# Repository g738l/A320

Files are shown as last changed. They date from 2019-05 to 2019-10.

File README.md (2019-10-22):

# A320
Simulation LED Anti-Collision Lighting System for Airbus A320 Family

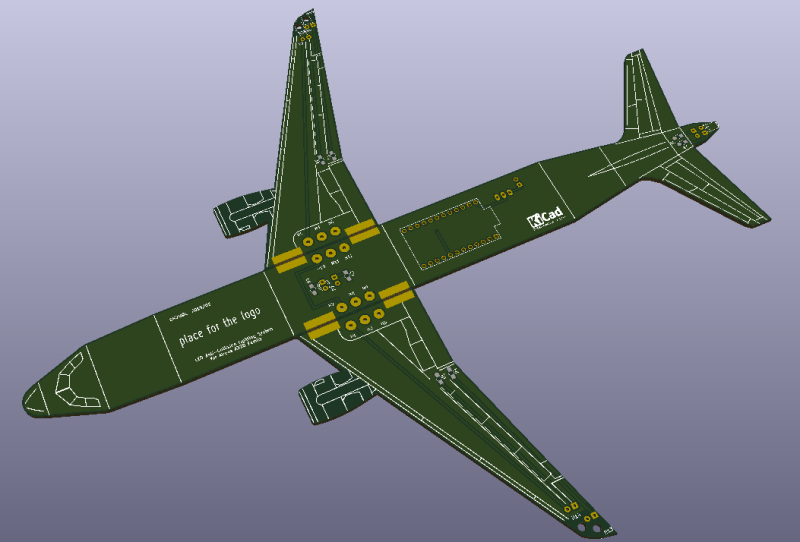
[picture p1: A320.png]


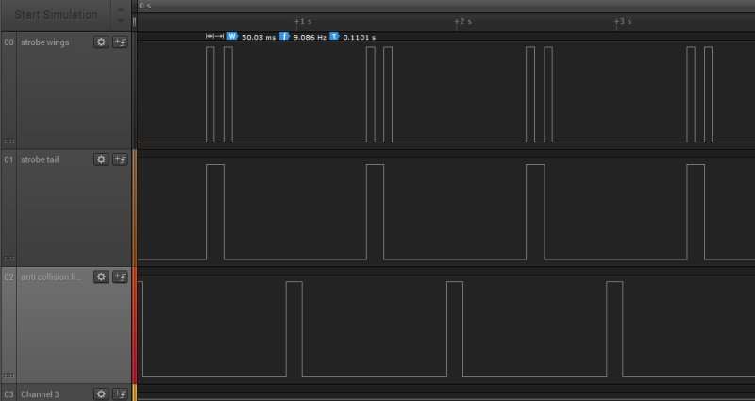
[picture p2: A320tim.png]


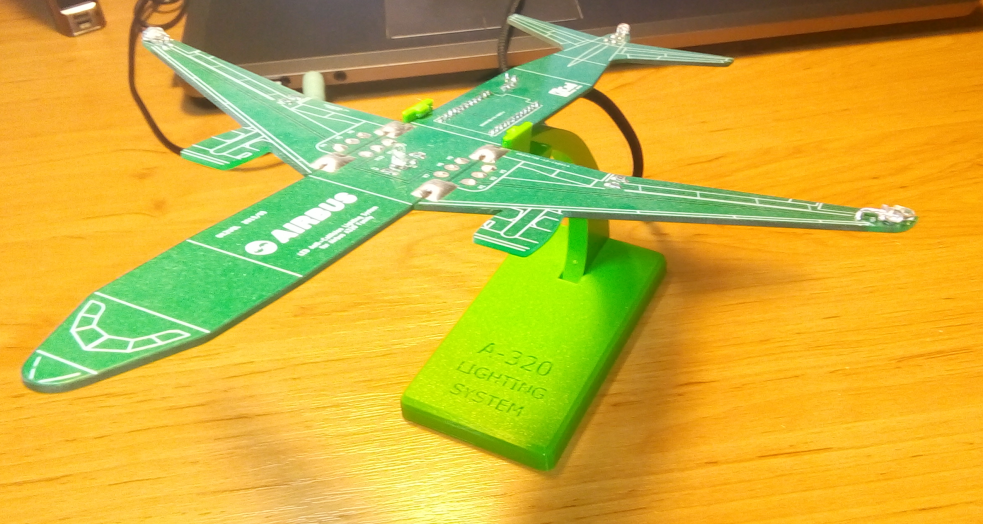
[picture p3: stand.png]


## License
This project is released under the Creative Commons Attribution-NonCommercial-ShareAlike 3.0 (CC-BY-NC-SA 3.0, https://creativecommons.org/licenses/by-nc-sa/3.0/) license. You may edit and share it as you like, as long as credit is given and the license is not changed. You can build as many boards for you and your friends as you like and you can even sell it to them to cover your costs, **however it is strictly forbidden to turn this into a commercial product! You are not allowed to build and sell these boards for profit!**

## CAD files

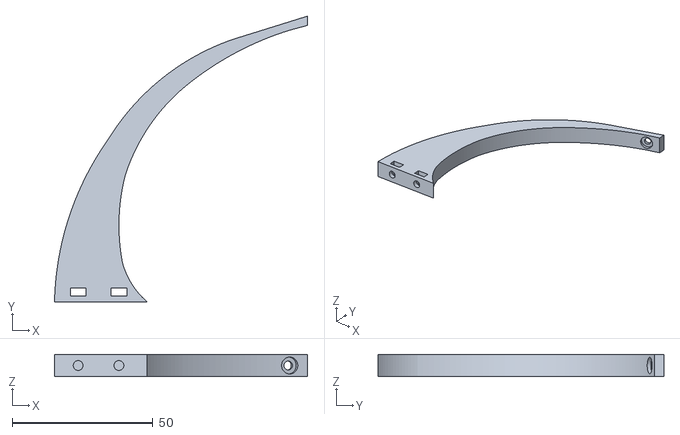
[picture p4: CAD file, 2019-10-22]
3Dstand/A320stand_upright.stl
90.0 x 101.7 x 8.00

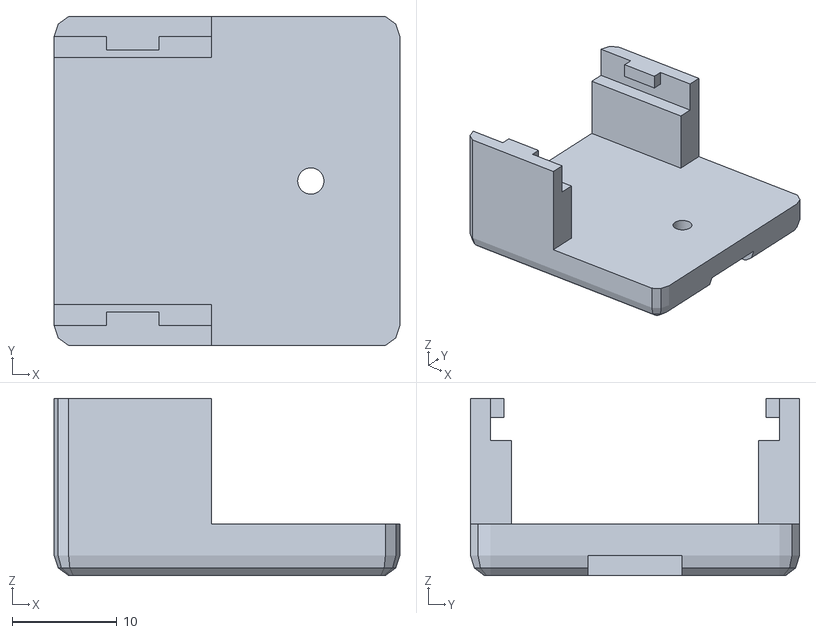
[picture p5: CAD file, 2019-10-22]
3Dstand/A320attachment.stl
33.0 x 31.4 x 16.9

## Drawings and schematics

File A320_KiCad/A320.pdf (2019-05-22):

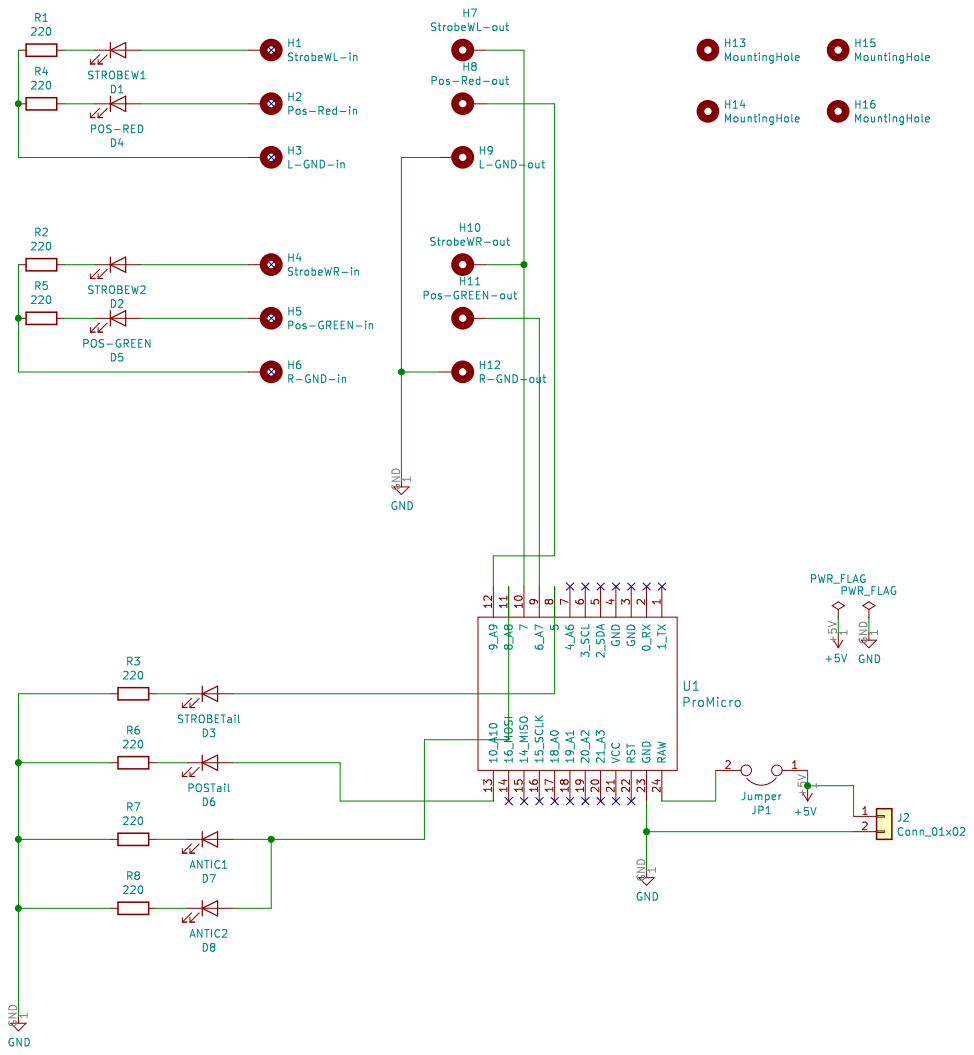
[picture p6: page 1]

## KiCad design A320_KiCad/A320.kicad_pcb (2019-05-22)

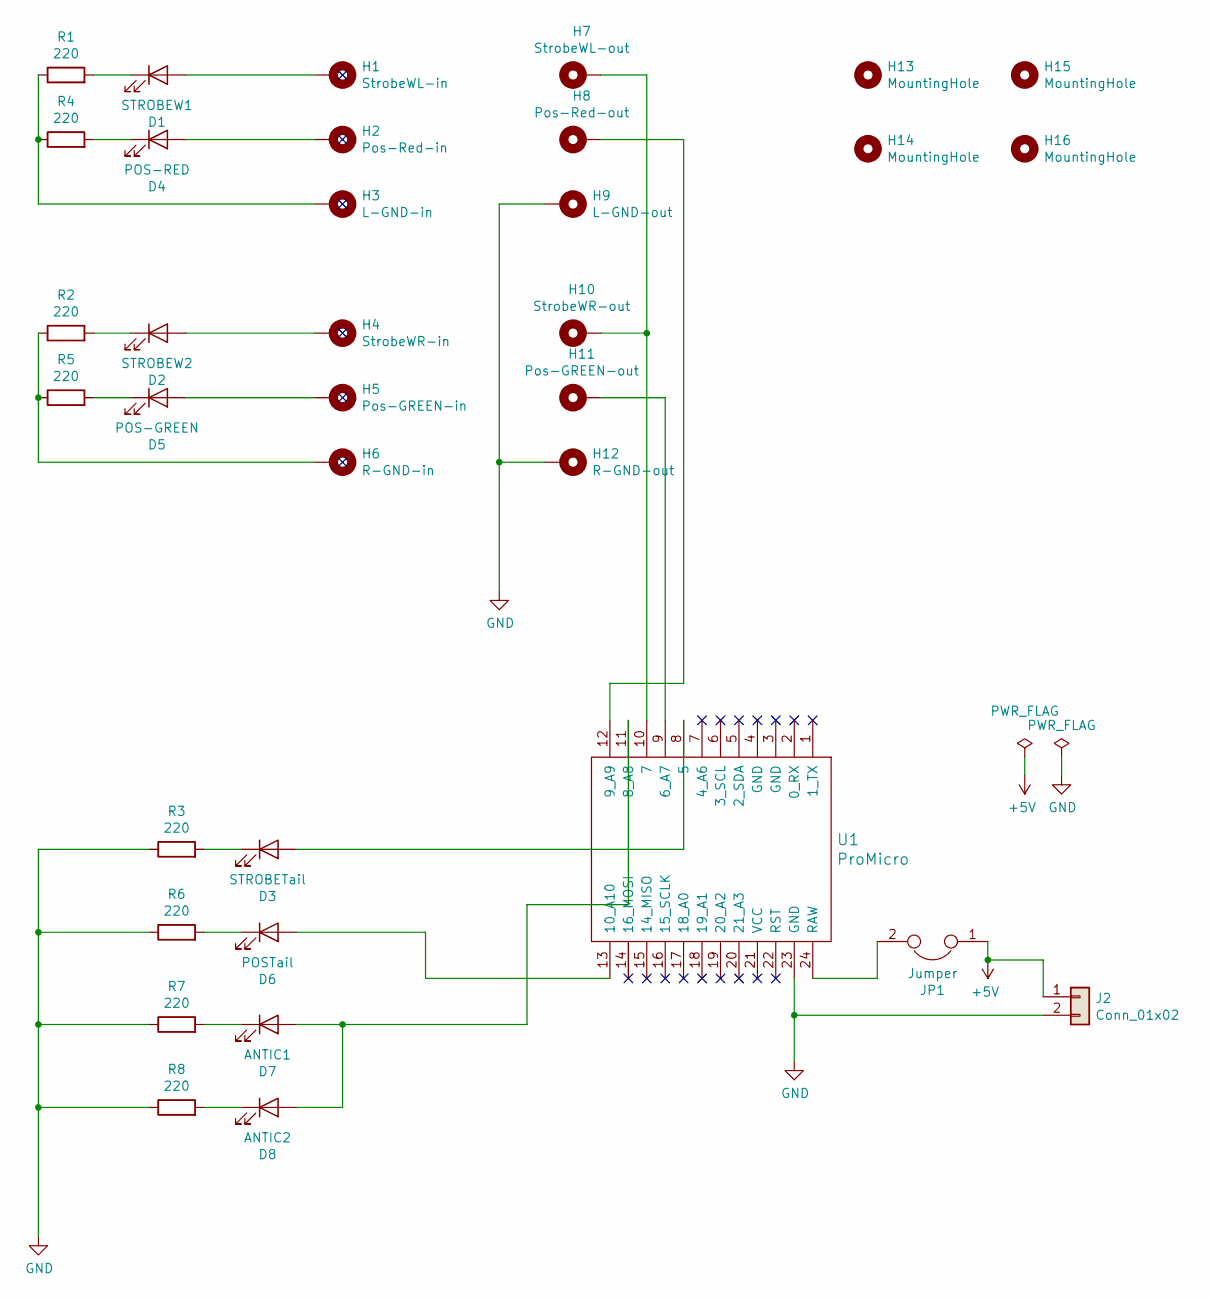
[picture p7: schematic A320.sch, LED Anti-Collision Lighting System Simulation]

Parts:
D1: STROBEW1; LED_D3.0mm_Horizontal_O3.81mm_Z2.0mm
D2: STROBEW2; LED_D3.0mm_Horizontal_O3.81mm_Z2.0mm
D3: STROBETail; LED_D3.0mm_Horizontal_O1.27mm_Z2.0mm
D4: POS-RED; LED_D3.0mm_Horizontal_O1.27mm_Z2.0mm
D5: POS-GREEN; LED_D3.0mm_Horizontal_O1.27mm_Z2.0mm
D6: POSTail; LED_D3.0mm_Horizontal_O3.81mm_Z2.0mm
D7: ANTIC1; LED_D3.0mm_FlatTop
D8: ANTIC2; LED_D3.0mm_FlatTop
H1: StrobeWL-in; SolderWirePad_single_1-2mmDrill
H2: Pos-Red-in; SolderWirePad_single_1-2mmDrill
H3: L-GND-in; SolderWirePad_single_1-2mmDrill
H4: StrobeWR-in; SolderWirePad_single_1-2mmDrill
H5: Pos-GREEN-in; SolderWirePad_single_1-2mmDrill
H6: R-GND-in; SolderWirePad_single_1-2mmDrill
H7: StrobeWL-out; SolderWirePad_single_1-2mmDrill
H8: Pos-Red-out; SolderWirePad_single_1-2mmDrill
H9: L-GND-out; SolderWirePad_single_1-2mmDrill
H10: StrobeWR-out; SolderWirePad_single_1-2mmDrill
H11: Pos-GREEN-out; SolderWirePad_single_1-2mmDrill
H12: R-GND-out; SolderWirePad_single_1-2mmDrill
H13, H14, H15, H16: MountingHole; MountingHole_2.5mm
J2: Conn_01x02; Pin_Header_Angled_1x02_Pitch2.54mm
JP1: Jumper; ON-OFF-SWITH
R1, R2, R3, R4, R5, R6, R7, R8: 220; R_0805_HandSoldering
U1: ProMicro

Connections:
+5V: J2.1, JP1.1
GND: H9.1, H12.1, J2.2, R3.1, R6.1, R7.1, R8.1, U1.23 (GND)
unnamed: D1.1 (K), R1.2
unnamed: D1.2 (A), H1.1
unnamed: D2.1 (K), R2.2
unnamed: D2.2 (A), H4.1
unnamed: D3.1 (K), R3.2
unnamed: D3.2 (A), U1.8 (5)
unnamed: D4.1 (K), R4.2
unnamed: D4.2 (A), H2.1
unnamed: D5.1 (K), R5.2
unnamed: D5.2 (A), H5.1
unnamed: D6.1 (K), R6.2
unnamed: D6.2 (A), U1.13 (10_A10)
unnamed: D7.1 (K), R7.2
unnamed: D7.2 (A), D8.2 (A), U1.11 (8_A8)
unnamed: D8.1 (K), R8.2
unnamed: H3.1, R1.1, R4.1
unnamed: H6.1, R2.1, R5.1
unnamed: H8.1, U1.12 (9_A9)
unnamed: H7.1, H10.1, U1.10 (7)
unnamed: H11.1, U1.9 (6_A7)
unnamed: JP1.2, U1.24 (RAW)

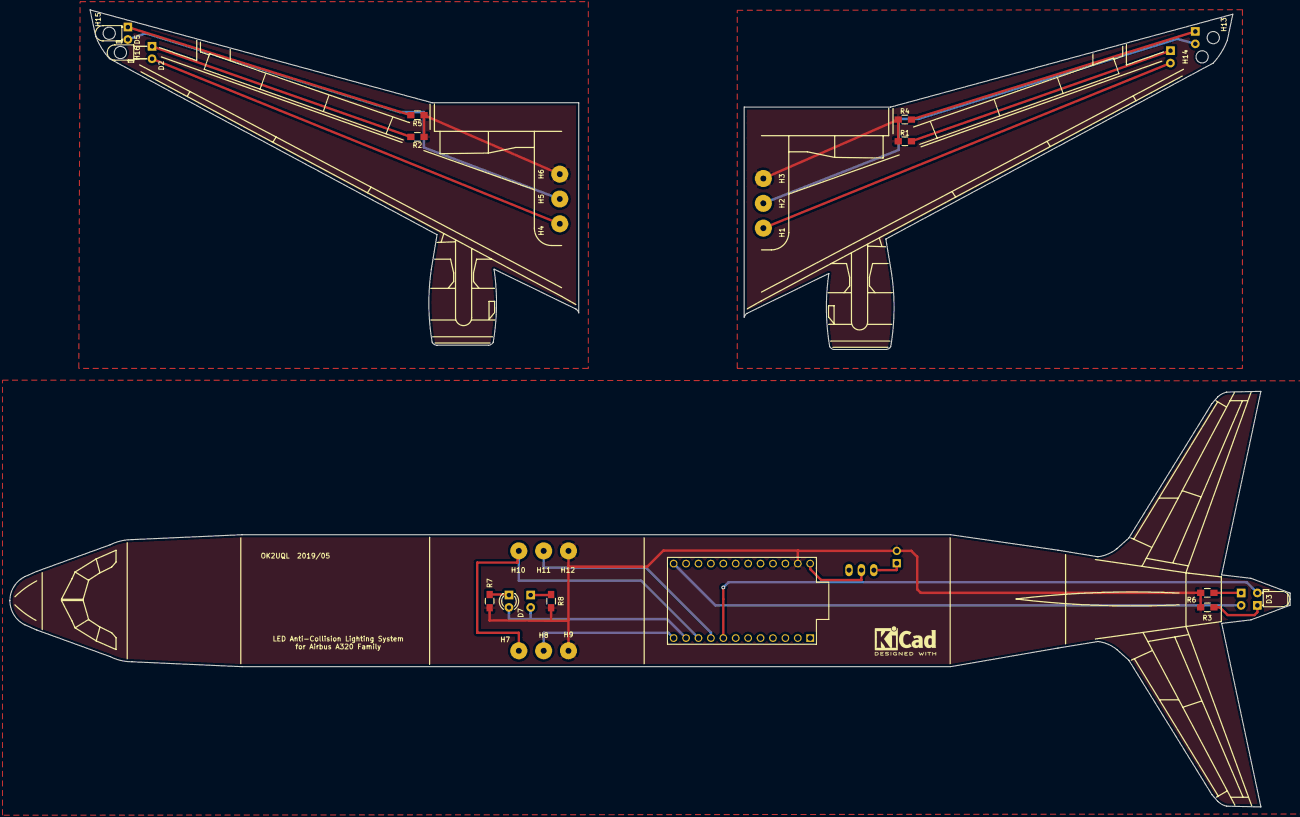
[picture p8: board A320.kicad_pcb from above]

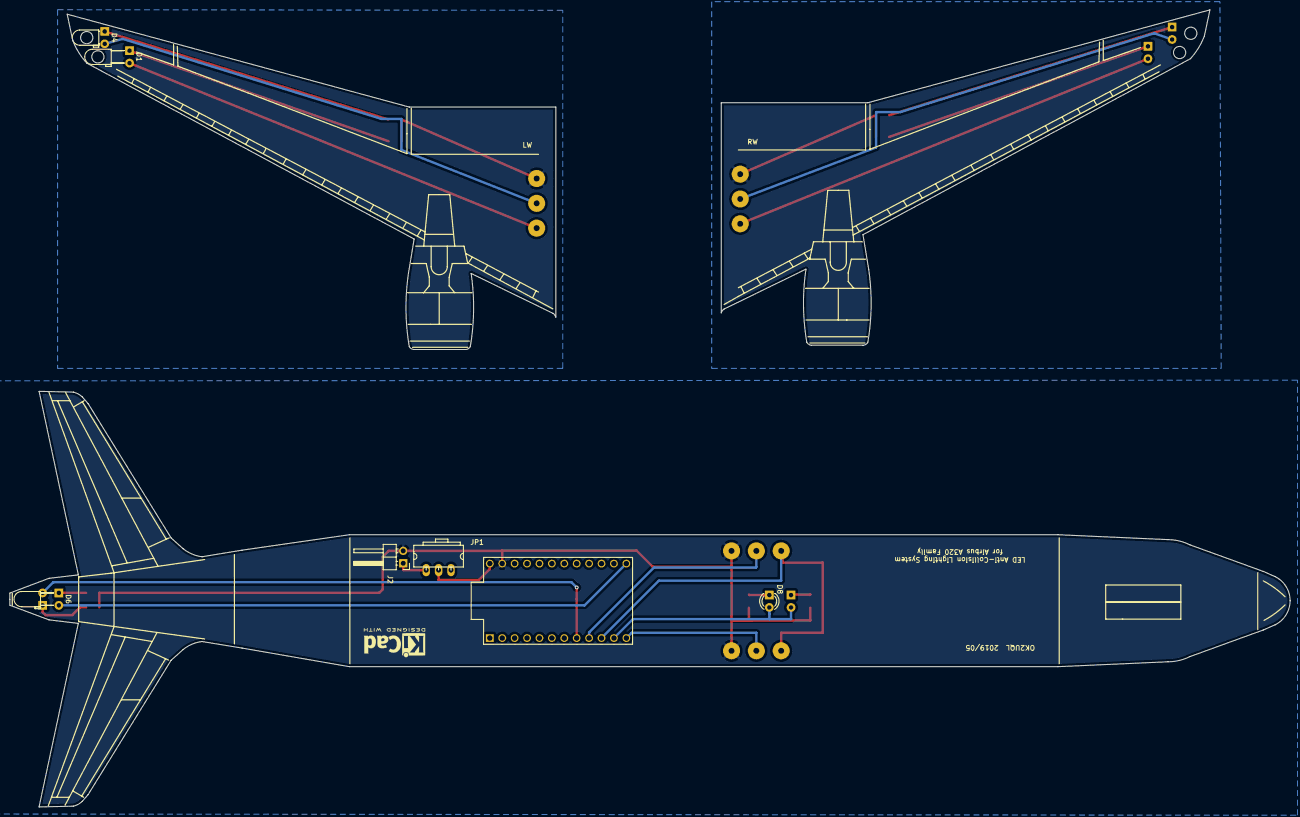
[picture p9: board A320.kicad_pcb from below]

Board: 2 copper layers, 262.0 x 163.1 mm, 35 parts (7 on the bottom side), 23 nets.

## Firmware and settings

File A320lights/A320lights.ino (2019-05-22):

/* Simulation LED Anti-Collision Lighting System for Airbus A320 Family
  LED Wing Strobe Lights 2LA456509-02 and 510-02 for Sharklet Wing Tips  double flash
  50 ms on – 60 ms off – 50 ms on
  LED Beacon Light 2LA455968-01  100 ms on 
  LED Rearward Strobe and Navigation Light 2LA456241-00 110 ms on
  ProMicro , ATmega32U4  3.3V/8MHz
  ProMicro , ATmega32U4  5V/16MHz
*/  
  
int poswhite = 10;
int posred = 9;
int posgreen = 6;
int strobe = 7;
int beacon = 8;
int tail = 5;

void setup()
{
  pinMode(strobe, OUTPUT);
  pinMode(beacon, OUTPUT);
  pinMode(tail, OUTPUT);
  pinMode(poswhite, OUTPUT);
  pinMode(posred, OUTPUT);
  pinMode(posgreen, OUTPUT);

  analogWrite(poswhite, 1); //set light intensity
  analogWrite(posred, 10); //set light intensity
  analogWrite(posgreen, 30); //set light intensity
}  
  
void loop() 
{
  digitalWrite(strobe, HIGH);
  digitalWrite(tail, HIGH);  
  delay(50);              
  digitalWrite(strobe, LOW);   
  delay(60);
  digitalWrite(tail, LOW);  
  digitalWrite(strobe, HIGH);  
  delay(50);              
  digitalWrite(strobe, LOW);    
  delay(340);
  digitalWrite(beacon, HIGH);
  delay(100);
  digitalWrite(beacon, LOW);
  delay(400);
}
